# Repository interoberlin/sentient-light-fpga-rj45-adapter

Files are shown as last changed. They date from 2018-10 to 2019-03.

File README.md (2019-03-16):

# Lattice iCEstick adapter with four RJ-45 sockets

The adapter in this repository takes sixteen 3V3 logic level input signals,
converts them to 5V and outputs them on four RJ-45 sockets, four signals per socket,
one signal per twisted pair of an off-the-shelf CAT-5 ethernet cable.
Eight additional inputs can switch the RJ-45 sockets' LEDs on and off.

## Pictures

### Top layer

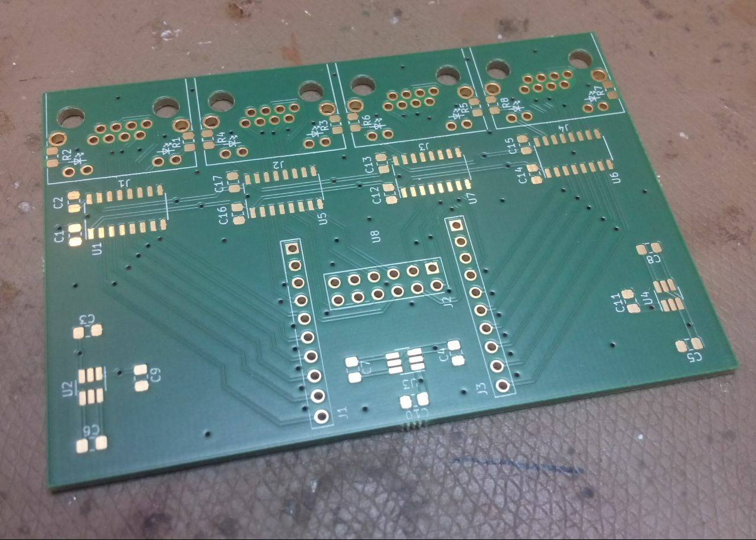
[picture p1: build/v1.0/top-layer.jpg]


### Bottom layer

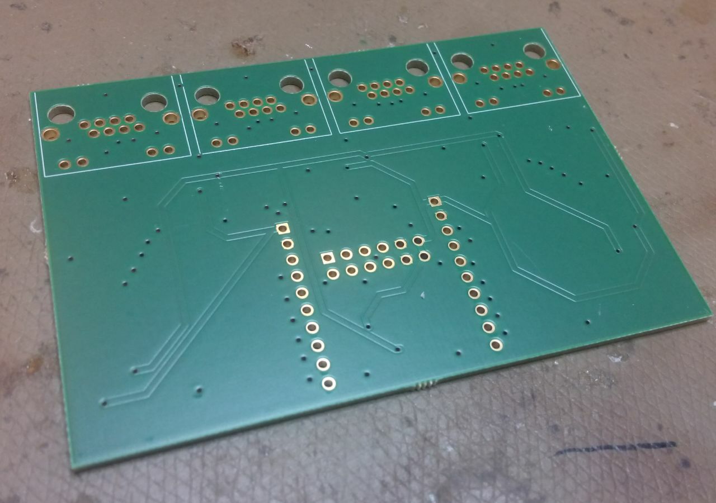
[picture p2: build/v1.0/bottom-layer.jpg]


### With components

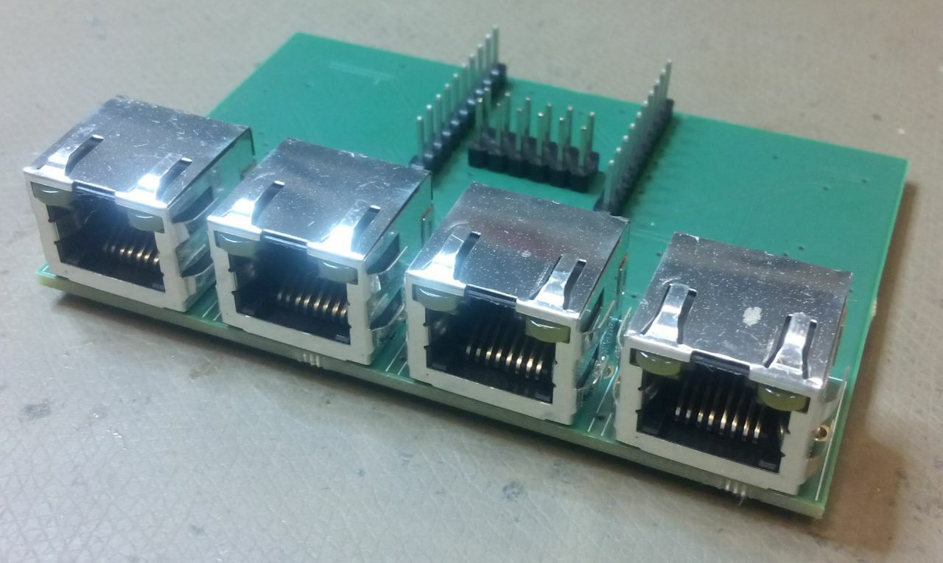
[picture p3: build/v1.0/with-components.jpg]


### With iCEstick

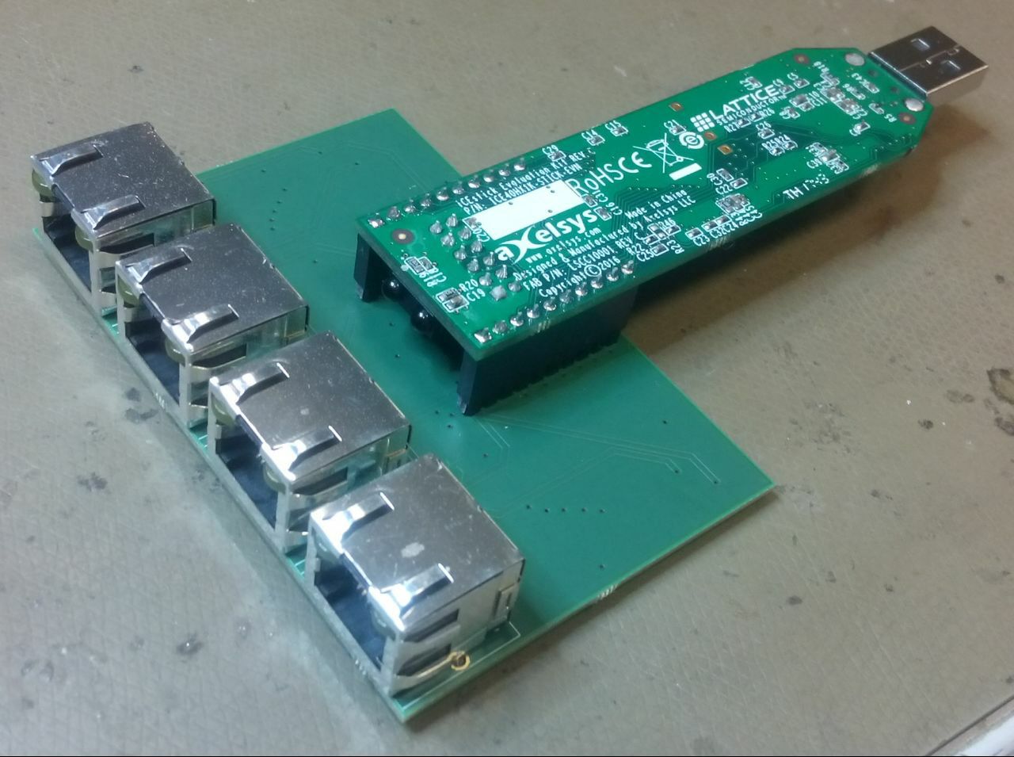
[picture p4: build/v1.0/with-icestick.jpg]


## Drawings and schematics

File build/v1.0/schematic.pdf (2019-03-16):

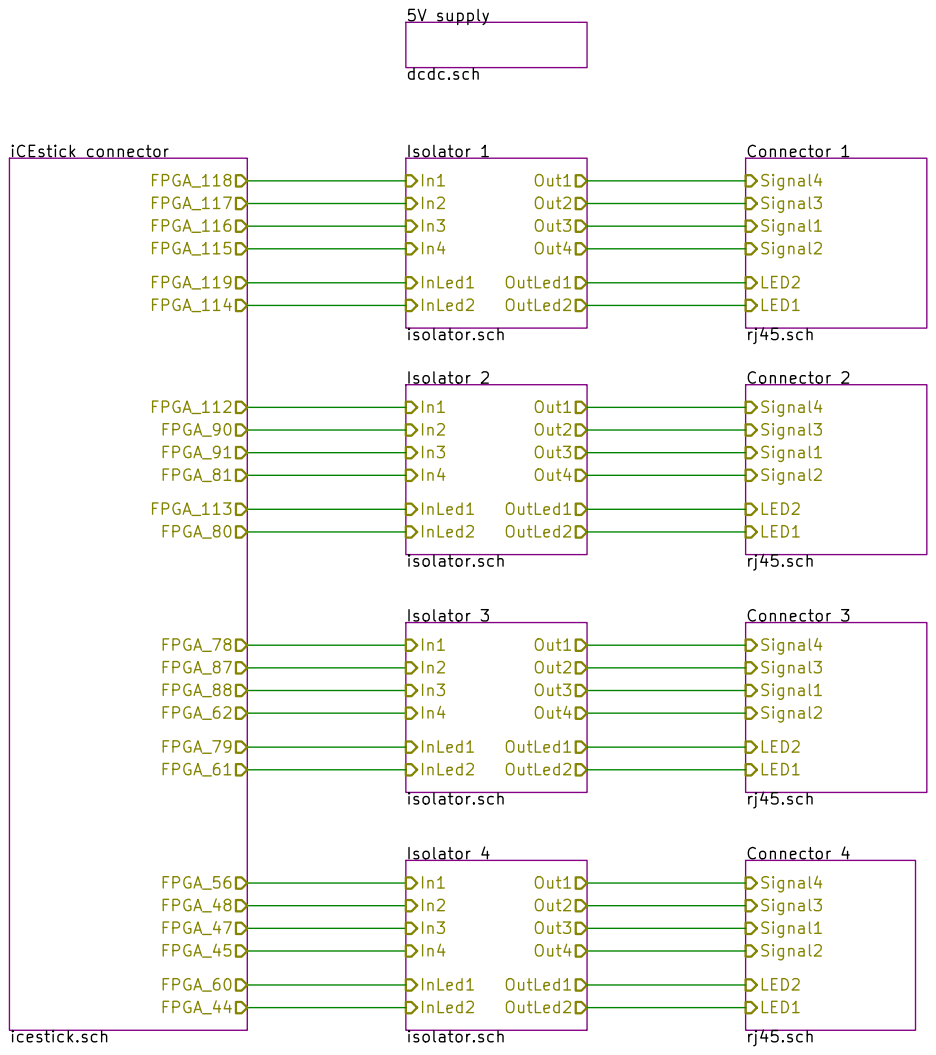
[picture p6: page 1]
6 ABCD; ABCD Date: KiCad E.D.A. kicad 5.0.1+dfsg1-2 Size: A4; Rev:; Id: 1/11 Title:; Isolator 1; isolator.sch; Out1 Out2 Out3 Out4; InLed1; OutLed1; InLed2; OutLed2; Isolator 2; Connector 1; rj45.sch; Signal1 Signal2; Signal3; Signal4; LED1; LED2 Connector 2; LED2 Connector 3; LED2 Connector 4; LED2; Isolator 4; Isolator 3; iCEstick connector; icestick.sch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

5V supply dcdc.sch

File: icestick-rj45-shield.sch Sheet: /

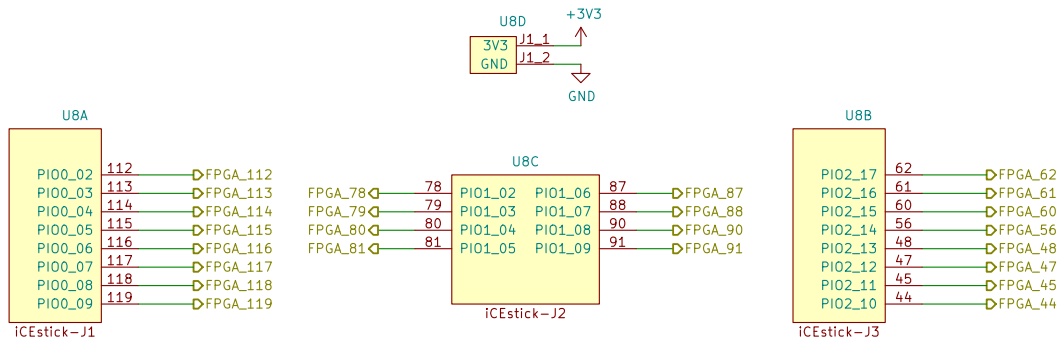
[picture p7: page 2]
D Date: KiCad E.D.A. kicad 5.0.1+dfsg1-2 Size: A4; Rev:; Id: 11/11 Title: File: icestick.sch Sheet: /iCEstick connector/ FPGA_112 FPGA_113 FPGA_114 FPGA_115 FPGA_116 FPGA_117 FPGA_118 FPGA_119; FPGA_62 FPGA_61 FPGA_60 FPGA_56 FPGA_48 FPGA_47 FPGA_45 FPGA_44 GND; FPGA_78 FPGA_79 FPGA_80 FPGA_81; FPGA_87 FPGA_88 FPGA_90 FPGA_91; iCEstick-J1 PIO0_02 112 PIO0_03 113 PIO0_04 114 PIO0_05 115 PIO0_06 116 PIO0_07 117 PIO0_08 118 PIO0_09 119 U8A; iCEstick-J3 PIO2_10; 44 PIO2_11; 45 PIO2_12; 47 PIO2_13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

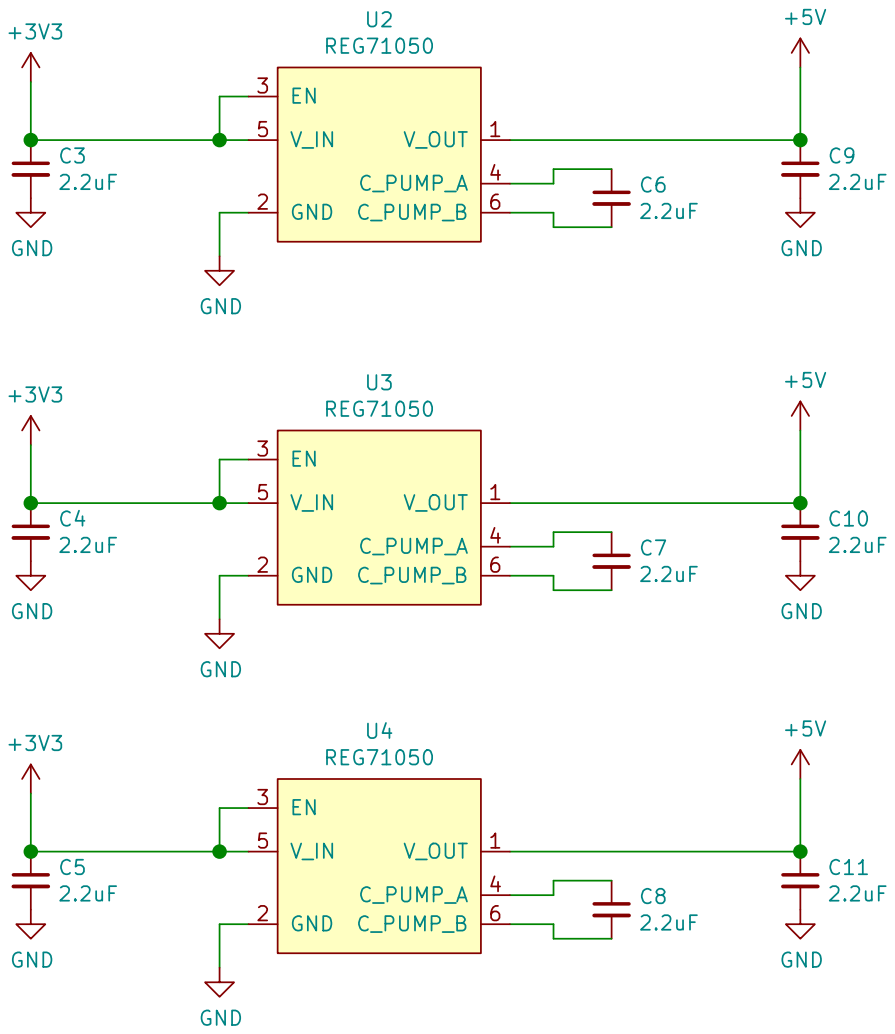
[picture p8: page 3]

Id: 3/11 Title: File: dcdc.sch Sheet: /5V supply/

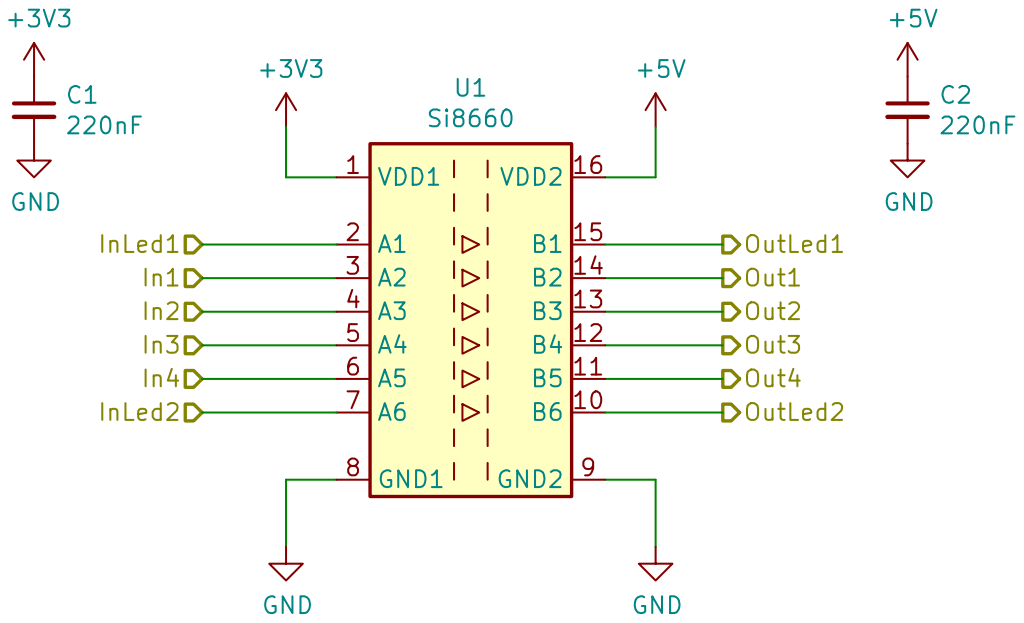
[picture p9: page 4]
D Date: KiCad E.D.A. kicad 5.0.1+dfsg1-2 Size: A4; Rev:; Out1 Out2 Out3 Out4 +3V3; +5V GND; GND; VDD1 1; B6 10 B5 11 B4 12 B3 13 B2 14 B1 15 VDD2 16 A1 2 A2 3 A3 4 A4 5 A5 6 A6 7 GND1 8; GND2 9 U1 Si8660; InLed1; OutLed1; InLed2; OutLed2

Id: 2/11 Title: File: isolator.sch Sheet: /Isolator 1/

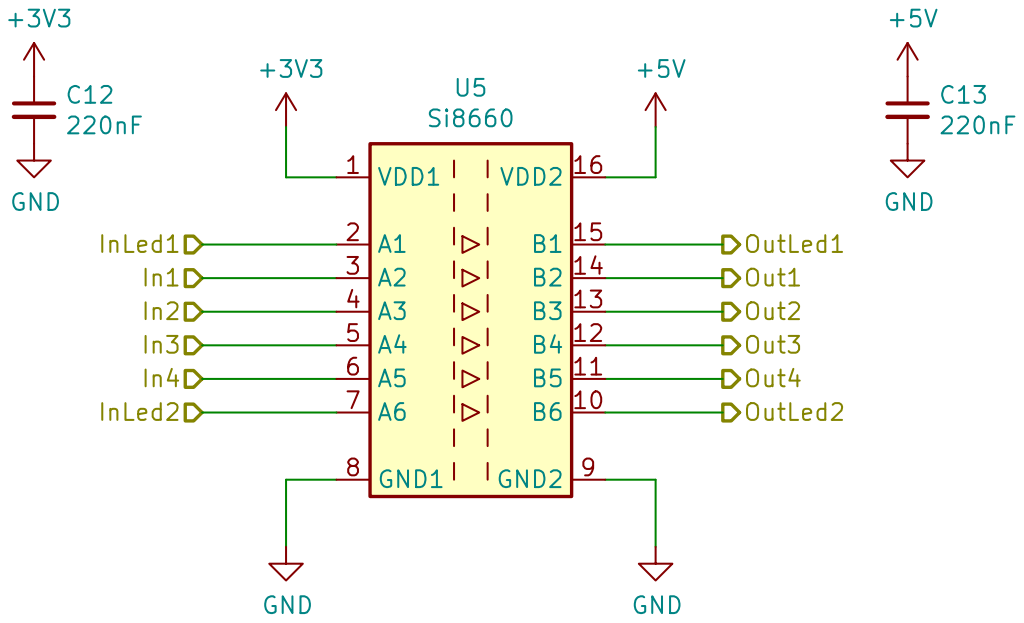
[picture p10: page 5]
D Date: KiCad E.D.A. kicad 5.0.1+dfsg1-2 Size: A4; Rev:; Out1 Out2 Out3 Out4 +3V3; +5V GND; GND; VDD1 1; B6 10 B5 11 B4 12 B3 13 B2 14 B1 15 VDD2 16 A1 2 A2 3 A3 4 A4 5 A5 6 A6 7 GND1 8; GND2 9 U5 Si8660; InLed1; OutLed1; InLed2; OutLed2

Id: 4/11 Title: File: isolator.sch Sheet: /Isolator 2/

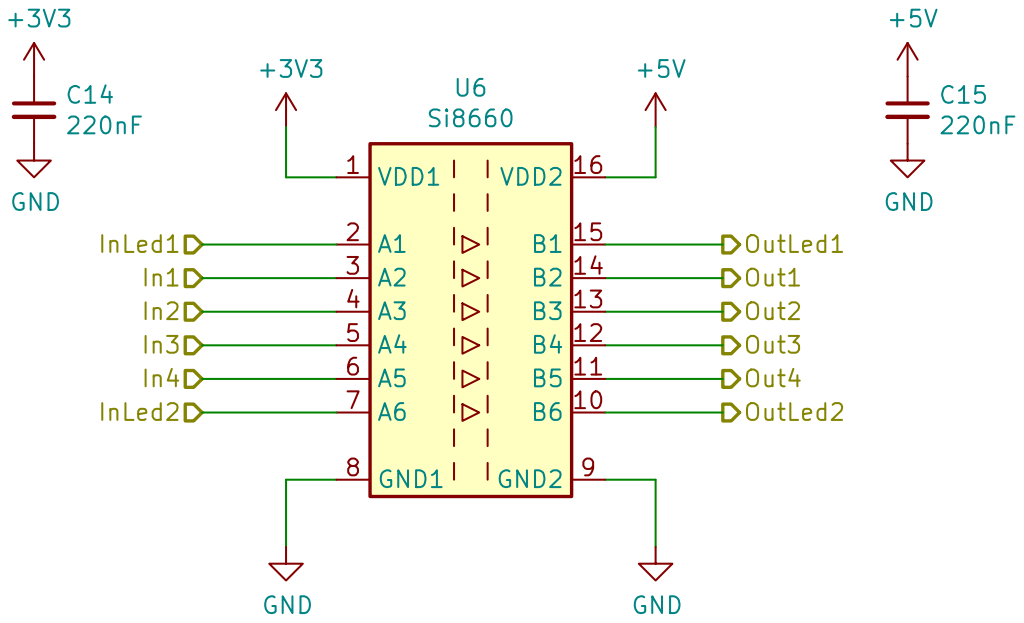
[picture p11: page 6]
D Date: KiCad E.D.A. kicad 5.0.1+dfsg1-2 Size: A4; Rev:; Out1 Out2 Out3 Out4 +3V3; +5V GND; GND; VDD1 1; B6 10 B5 11 B4 12 B3 13 B2 14 B1 15 VDD2 16 A1 2 A2 3 A3 4 A4 5 A5 6 A6 7 GND1 8; GND2 9 U6 Si8660; InLed1; OutLed1; InLed2; OutLed2

Id: 9/11 Title: File: isolator.sch Sheet: /Isolator 4/

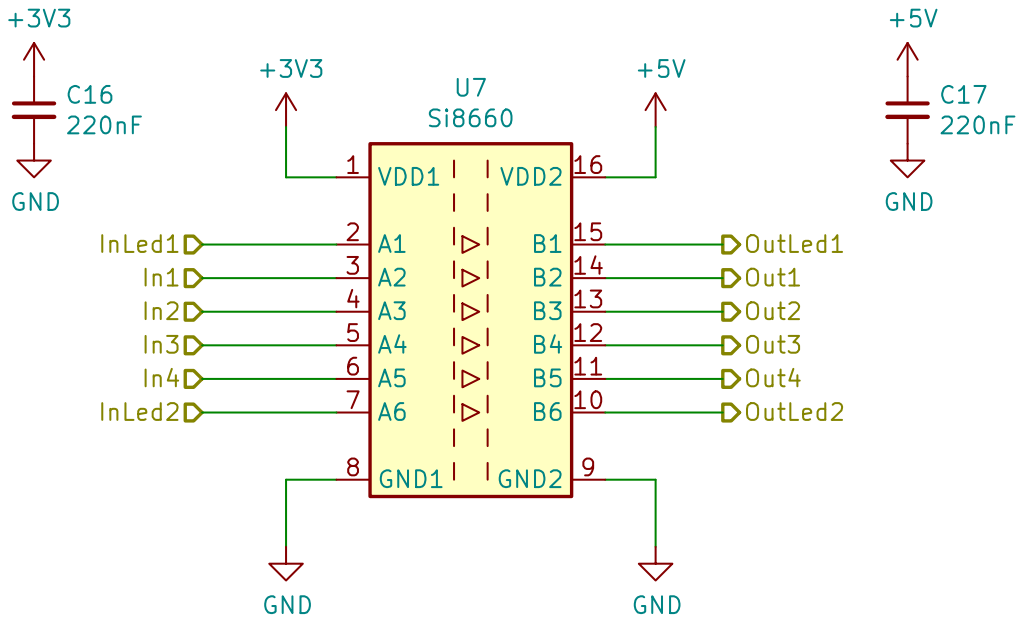
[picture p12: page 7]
D Date: KiCad E.D.A. kicad 5.0.1+dfsg1-2 Size: A4; Rev:; Out1 Out2 Out3 Out4 +3V3; +5V GND; GND; VDD1 1; B6 10 B5 11 B4 12 B3 13 B2 14 B1 15 VDD2 16 A1 2 A2 3 A3 4 A4 5 A5 6 A6 7 GND1 8; GND2 9 U7 Si8660; InLed1; OutLed1; InLed2; OutLed2

Id: 10/11 Title: File: isolator.sch Sheet: /Isolator 3/

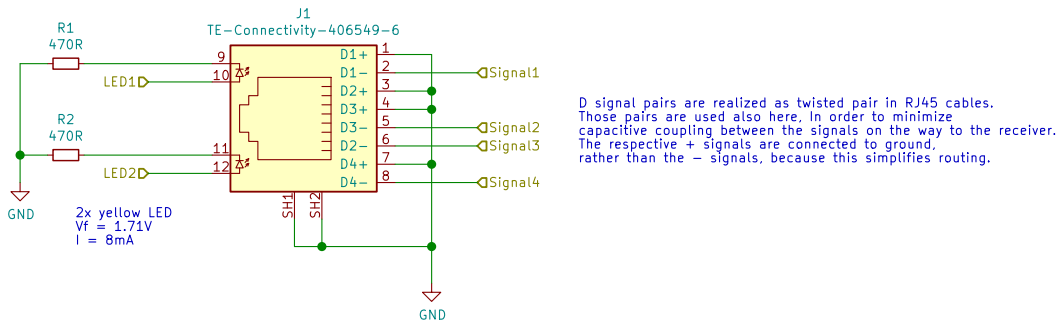
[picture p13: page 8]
D Date: KiCad E.D.A. kicad 5.0.1+dfsg1-2 Size: A4; Rev:; Signal1; Signal2 Signal3; Signal4 GND; LED1; LED2 R1 470R; R2 470R GND; SH¹; SH²; J1 TE-Connectivity-406549-6; 2x yellow LED Vf = 1.71V; D signal pairs are realized as twisted pair in RJ45 cables.

Those pairs are used also here, In order to minimize
capacitive coupling between the signals on the way to the receiver.
The respective + signals are connected to ground,
rather than the - signals, because this simplifies routing.

File: rj45.sch Sheet: /Connector 1/
Id: 5/11 Title:

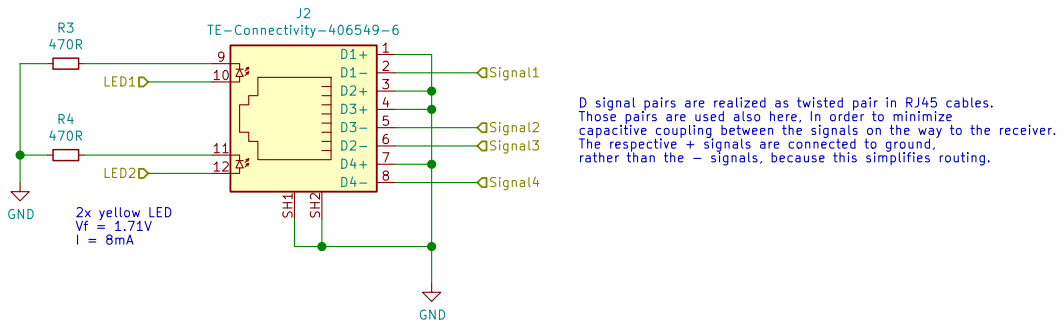
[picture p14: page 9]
D Date: KiCad E.D.A. kicad 5.0.1+dfsg1-2 Size: A4; Rev:; Signal1; Signal2 Signal3; Signal4 GND; LED1; LED2 R3 470R; R4 470R GND; SH¹; SH²; J2 TE-Connectivity-406549-6; 2x yellow LED Vf = 1.71V; D signal pairs are realized as twisted pair in RJ45 cables.

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

File: rj45.sch Sheet: /Connector 2/
Id: 6/11 Title:

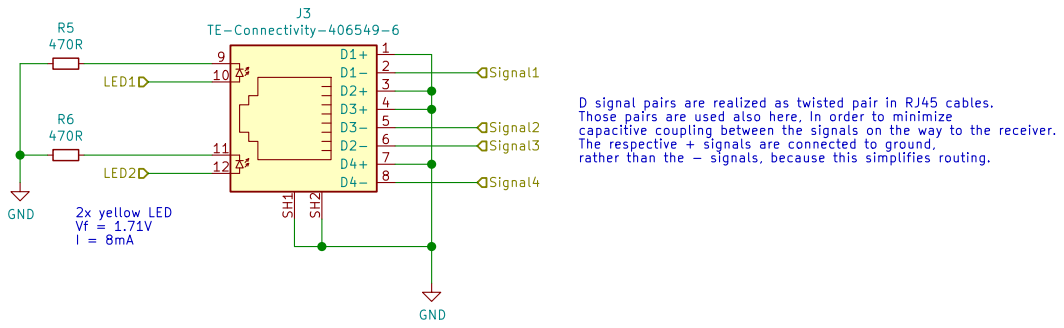
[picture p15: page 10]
D Date: KiCad E.D.A. kicad 5.0.1+dfsg1-2 Size: A4; Rev:; Signal1; Signal2 Signal3; Signal4 GND; LED1; LED2 R5 470R; R6 470R GND; SH¹; SH²; J3 TE-Connectivity-406549-6; 2x yellow LED Vf = 1.71V; D signal pairs are realized as twisted pair in RJ45 cables.

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

File: rj45.sch Sheet: /Connector 3/
Id: 7/11 Title:

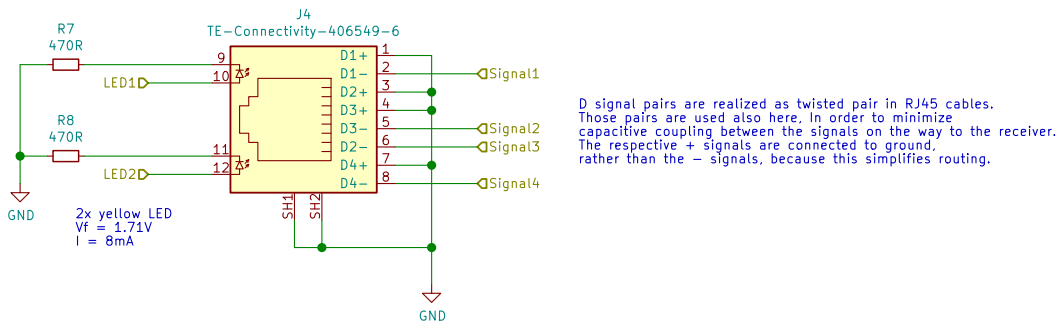
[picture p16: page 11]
D Date: KiCad E.D.A. kicad 5.0.1+dfsg1-2 Size: A4; Rev:; Signal1; Signal2 Signal3; Signal4 GND; LED1; LED2 R7 470R; R8 470R GND; SH¹; SH²; J4 TE-Connectivity-406549-6; 2x yellow LED Vf = 1.71V; D signal pairs are realized as twisted pair in RJ45 cables.

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

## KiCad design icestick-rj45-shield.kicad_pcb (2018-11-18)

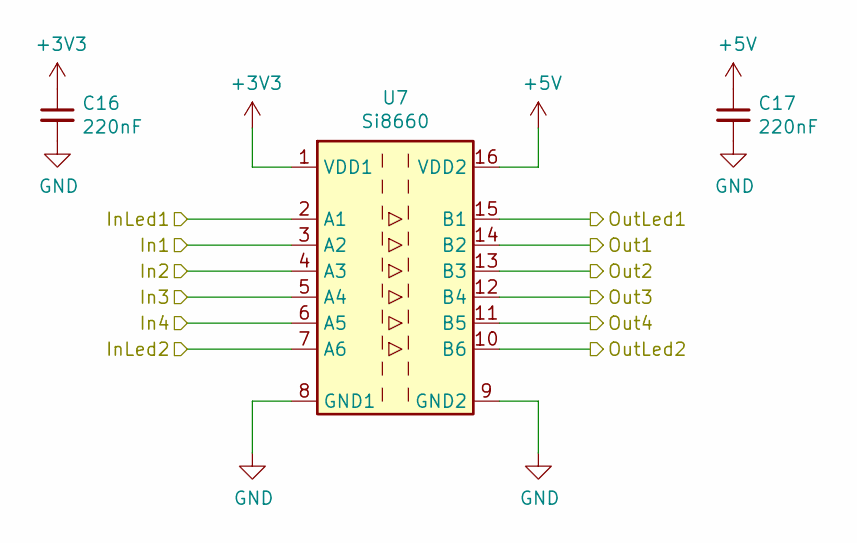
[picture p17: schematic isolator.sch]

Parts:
C1, C2: 220nF; C_0805_2012Metric_Pad1.15x1.40mm_HandSolder
U1: Si8660; SOIC-16_3.9x9.9mm_P1.27mm

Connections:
+3V3: C1.1, U1.1 (VDD1); also elsewhere on the board
+5V: C2.1, U1.16 (VDD2); also elsewhere on the board
/Connector 1/LED1: U1.10 (B6); also elsewhere on the board
/Connector 1/LED2: U1.15 (B1); also elsewhere on the board
/Isolator 1/Out1: U1.14 (B2); also elsewhere on the board
/Isolator 1/Out2: U1.13 (B3); also elsewhere on the board
/Isolator 1/Out3: U1.12 (B4); also elsewhere on the board
/Isolator 1/Out4: U1.11 (B5); also elsewhere on the board
/iCEstick connector/FPGA_114: U1.7 (A6); also elsewhere on the board
/iCEstick connector/FPGA_115: U1.6 (A5); also elsewhere on the board
/iCEstick connector/FPGA_116: U1.5 (A4); also elsewhere on the board
/iCEstick connector/FPGA_117: U1.4 (A3); also elsewhere on the board
/iCEstick connector/FPGA_118: U1.3 (A2); also elsewhere on the board
/iCEstick connector/FPGA_119: U1.2 (A1); also elsewhere on the board
GND: C1.2, C2.2, U1.8 (GND1), U1.9 (GND2); also elsewhere on the board

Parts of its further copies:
C12, C13, C14, C15, C16, C17: 220nF; C_0805_2012Metric_Pad1.15x1.40mm_HandSolder
U5, U6, U7: Si8660; SOIC-16_3.9x9.9mm_P1.27mm

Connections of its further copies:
+3V3: C12.1, C14.1, C16.1, U5.1 (VDD1), U6.1 (VDD1), U7.1 (VDD1); also elsewhere on the board
+5V: C13.1, C15.1, C17.1, U5.16 (VDD2), U6.16 (VDD2), U7.16 (VDD2); also elsewhere on the board
/Connector 2/LED1: U5.10 (B6); also elsewhere on the board
/Connector 2/LED2: U5.15 (B1); also elsewhere on the board
/Connector 3/LED1: U7.10 (B6); also elsewhere on the board
/Connector 3/LED2: U7.15 (B1); also elsewhere on the board
/Connector 4/LED1: U6.10 (B6); also elsewhere on the board
/Connector 4/LED2: U6.15 (B1); also elsewhere on the board
/Isolator 2/Out1: U5.14 (B2); also elsewhere on the board
/Isolator 2/Out2: U5.13 (B3); also elsewhere on the board
/Isolator 2/Out3: U5.12 (B4); also elsewhere on the board
/Isolator 2/Out4: U5.11 (B5); also elsewhere on the board
/Isolator 3/Out1: U7.14 (B2); also elsewhere on the board
/Isolator 3/Out2: U7.13 (B3); also elsewhere on the board
/Isolator 3/Out3: U7.12 (B4); also elsewhere on the board
/Isolator 3/Out4: U7.11 (B5); also elsewhere on the board
/Isolator 4/Out1: U6.14 (B2); also elsewhere on the board
/Isolator 4/Out2: U6.13 (B3); also elsewhere on the board
/Isolator 4/Out3: U6.12 (B4); also elsewhere on the board
/Isolator 4/Out4: U6.11 (B5); also elsewhere on the board
/iCEstick connector/FPGA_44: U6.7 (A6); also elsewhere on the board
/iCEstick connector/FPGA_45: U6.6 (A5); also elsewhere on the board
/iCEstick connector/FPGA_47: U6.5 (A4); also elsewhere on the board
/iCEstick connector/FPGA_48: U6.4 (A3); also elsewhere on the board
/iCEstick connector/FPGA_56: U6.3 (A2); also elsewhere on the board
/iCEstick connector/FPGA_60: U6.2 (A1); also elsewhere on the board
/iCEstick connector/FPGA_61: U7.7 (A6); also elsewhere on the board
/iCEstick connector/FPGA_62: U7.6 (A5); also elsewhere on the board
/iCEstick connector/FPGA_78: U7.3 (A2); also elsewhere on the board
/iCEstick connector/FPGA_79: U7.2 (A1); also elsewhere on the board
/iCEstick connector/FPGA_80: U5.7 (A6); also elsewhere on the board
/iCEstick connector/FPGA_81: U5.6 (A5); also elsewhere on the board
/iCEstick connector/FPGA_87: U7.4 (A3); also elsewhere on the board
/iCEstick connector/FPGA_88: U7.5 (A4); also elsewhere on the board
/iCEstick connector/FPGA_90: U5.4 (A3); also elsewhere on the board
/iCEstick connector/FPGA_91: U5.5 (A4); also elsewhere on the board
/iCEstick connector/FPGA_112: U5.3 (A2); also elsewhere on the board
/iCEstick connector/FPGA_113: U5.2 (A1); also elsewhere on the board
GND: C12.2, C13.2, C14.2, C15.2, C16.2, C17.2, U5.8 (GND1), U5.9 (GND2), U6.8 (GND1), U6.9 (GND2), U7.8 (GND1), U7.9 (GND2); also elsewhere on the board

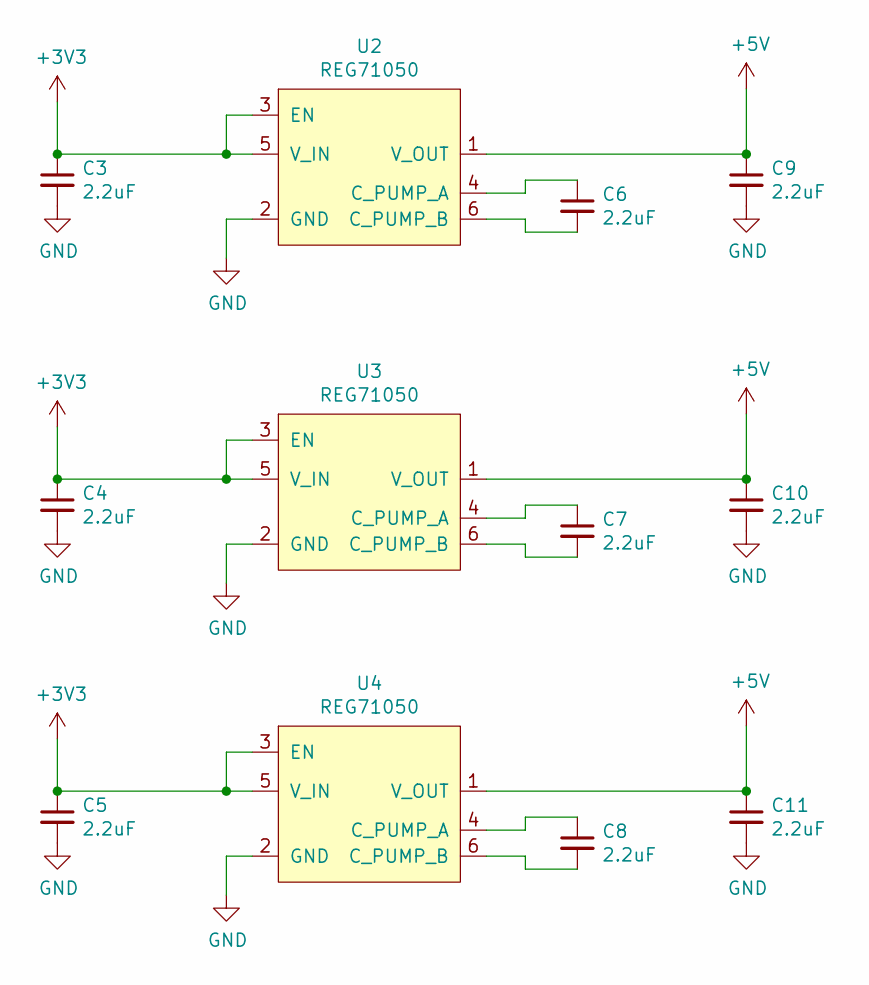
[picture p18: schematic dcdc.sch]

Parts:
C3, C4, C5, C6, C7, C8, C9, C10, C11: 2.2uF; C_0805_2012Metric_Pad1.15x1.40mm_HandSolder
U2, U3, U4: REG71050; SOT-23-6_Handsoldering

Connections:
+3V3: C3.1, C4.1, C5.1, U2.3 (EN), U2.5 (V_IN), U3.3 (EN), U3.5 (V_IN), U4.3 (EN), U4.5 (V_IN); also elsewhere on the board
+5V: C9.1, C10.1, C11.1, U2.1 (V_OUT), U3.1 (V_OUT), U4.1 (V_OUT); also elsewhere on the board
GND: C3.2, C4.2, C5.2, C9.2, C10.2, C11.2, U2.2 (GND), U3.2 (GND), U4.2 (GND); also elsewhere on the board
unnamed: C6.1, U2.4 (C_PUMP_A)
unnamed: C6.2, U2.6 (C_PUMP_B)
unnamed: C7.1, U3.4 (C_PUMP_A)
unnamed: C7.2, U3.6 (C_PUMP_B)
unnamed: C8.1, U4.4 (C_PUMP_A)
unnamed: C8.2, U4.6 (C_PUMP_B)

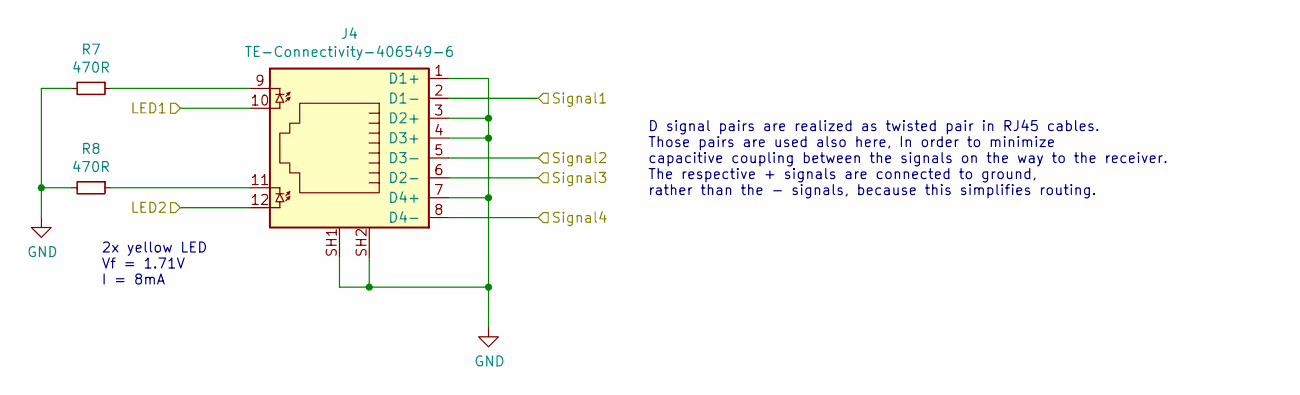
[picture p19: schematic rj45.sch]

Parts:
J2: TE-Connectivity-406549-6
R1, R2: 470R; R_0805_2012Metric_Pad1.15x1.40mm_HandSolder

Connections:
/Connector 2/LED1: J2.10; also elsewhere on the board
/Connector 2/LED2: J2.12; also elsewhere on the board
/Isolator 2/Out1: J2.8 (D4-); also elsewhere on the board
/Isolator 2/Out2: J2.6 (D2-); also elsewhere on the board
/Isolator 2/Out3: J2.2 (D1-); also elsewhere on the board
/Isolator 2/Out4: J2.5 (D3-); also elsewhere on the board
GND: J2.1 (D1+), J2.3 (D2+), J2.4 (D3+), J2.7 (D4+), J2.SH1, J2.SH2, R1.2, R2.2; also elsewhere on the board

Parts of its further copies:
J1, J3, J4: TE-Connectivity-406549-6
R3, R4, R5, R6, R7, R8: 470R; R_0805_2012Metric_Pad1.15x1.40mm_HandSolder

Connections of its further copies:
/Connector 1/LED1: J1.10; also elsewhere on the board
/Connector 1/LED2: J1.12; also elsewhere on the board
/Connector 3/LED1: J3.10; also elsewhere on the board
/Connector 3/LED2: J3.12; also elsewhere on the board
/Connector 4/LED1: J4.10; also elsewhere on the board
/Connector 4/LED2: J4.12; also elsewhere on the board
/Isolator 1/Out1: J1.8 (D4-); also elsewhere on the board
/Isolator 1/Out2: J1.6 (D2-); also elsewhere on the board
/Isolator 1/Out3: J1.2 (D1-); also elsewhere on the board
/Isolator 1/Out4: J1.5 (D3-); also elsewhere on the board
/Isolator 3/Out1: J3.8 (D4-); also elsewhere on the board
/Isolator 3/Out2: J3.6 (D2-); also elsewhere on the board
/Isolator 3/Out3: J3.2 (D1-); also elsewhere on the board
/Isolator 3/Out4: J3.5 (D3-); also elsewhere on the board
/Isolator 4/Out1: J4.8 (D4-); also elsewhere on the board
/Isolator 4/Out2: J4.6 (D2-); also elsewhere on the board
/Isolator 4/Out3: J4.2 (D1-); also elsewhere on the board
/Isolator 4/Out4: J4.5 (D3-); also elsewhere on the board
GND: J1.1 (D1+), J1.3 (D2+), J1.4 (D3+), J1.7 (D4+), J1.SH1, J1.SH2, J3.1 (D1+), J3.3 (D2+), J3.4 (D3+), J3.7 (D4+), J3.SH1, J3.SH2, J4.1 (D1+), J4.3 (D2+), J4.4 (D3+), J4.7 (D4+), J4.SH1, J4.SH2, R3.2, R4.2, R5.2, R6.2, R7.2, R8.2; also elsewhere on the board
unnamed: J3.9, R5.1
unnamed: J3.11, R6.1
unnamed: J4.9, R7.1
unnamed: J4.11, R8.1

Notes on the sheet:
2x yellow LED Vf = 1.71V I = 8mA
D signal pairs are realized as twisted pair in RJ45 cables. Those pairs are used also here, In order to minimize capacitive coupling between the signals on the way to the receiver. The respective + signals are connected to ground, rather than the - signals, because this simplifies routing.

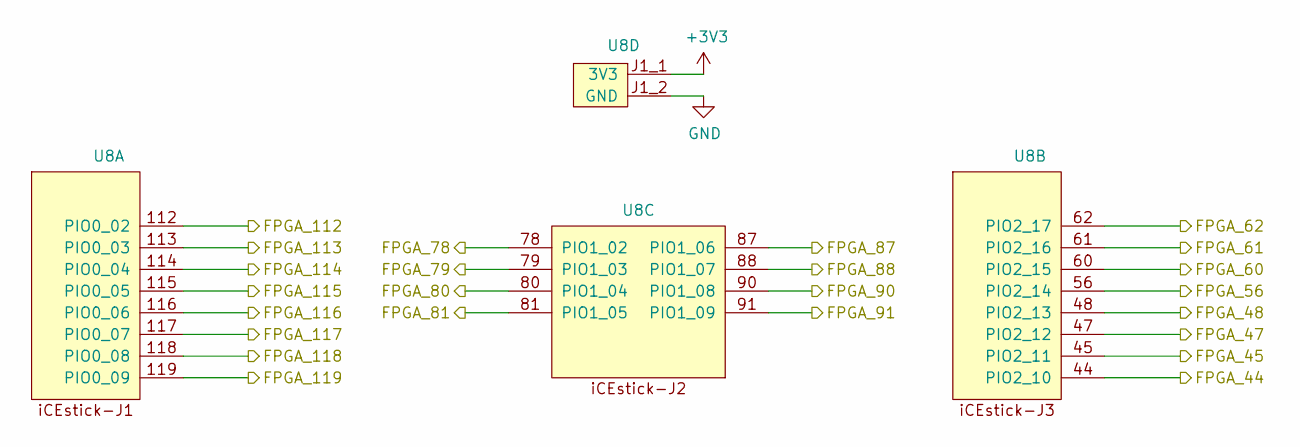
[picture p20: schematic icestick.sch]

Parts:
U8: iCEstick

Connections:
+3V3: U8.J1_1 (3V3), U8.J2_6 (3V3), U8.J2_12 (3V3), U8.J3_1 (3V3); also elsewhere on the board
/iCEstick connector/FPGA_44: U8.44 (PIO2_10); also elsewhere on the board
/iCEstick connector/FPGA_45: U8.45 (PIO2_11); also elsewhere on the board
/iCEstick connector/FPGA_47: U8.47 (PIO2_12); also elsewhere on the board
/iCEstick connector/FPGA_48: U8.48 (PIO2_13); also elsewhere on the board
/iCEstick connector/FPGA_56: U8.56 (PIO2_14); also elsewhere on the board
/iCEstick connector/FPGA_60: U8.60 (PIO2_15); also elsewhere on the board
/iCEstick connector/FPGA_61: U8.61 (PIO2_16); also elsewhere on the board
/iCEstick connector/FPGA_62: U8.62 (PIO2_17); also elsewhere on the board
/iCEstick connector/FPGA_78: U8.78 (PIO1_02); also elsewhere on the board
/iCEstick connector/FPGA_79: U8.79 (PIO1_03); also elsewhere on the board
/iCEstick connector/FPGA_80: U8.80 (PIO1_04); also elsewhere on the board
/iCEstick connector/FPGA_81: U8.81 (PIO1_05); also elsewhere on the board
/iCEstick connector/FPGA_87: U8.87 (PIO1_06); also elsewhere on the board
/iCEstick connector/FPGA_88: U8.88 (PIO1_07); also elsewhere on the board
/iCEstick connector/FPGA_90: U8.90 (PIO1_08); also elsewhere on the board
/iCEstick connector/FPGA_91: U8.91 (PIO1_09); also elsewhere on the board
/iCEstick connector/FPGA_112: U8.112 (PIO0_02); also elsewhere on the board
/iCEstick connector/FPGA_113: U8.113 (PIO0_03); also elsewhere on the board
/iCEstick connector/FPGA_114: U8.114 (PIO0_04); also elsewhere on the board
/iCEstick connector/FPGA_115: U8.115 (PIO0_05); also elsewhere on the board
/iCEstick connector/FPGA_116: U8.116 (PIO0_06); also elsewhere on the board
/iCEstick connector/FPGA_117: U8.117 (PIO0_07); also elsewhere on the board
/iCEstick connector/FPGA_118: U8.118 (PIO0_08); also elsewhere on the board
/iCEstick connector/FPGA_119: U8.119 (PIO0_09); also elsewhere on the board
GND: U8.J1_2 (GND), U8.J2_5 (GND), U8.J2_11 (GND), U8.J3_2 (GND); also elsewhere on the board

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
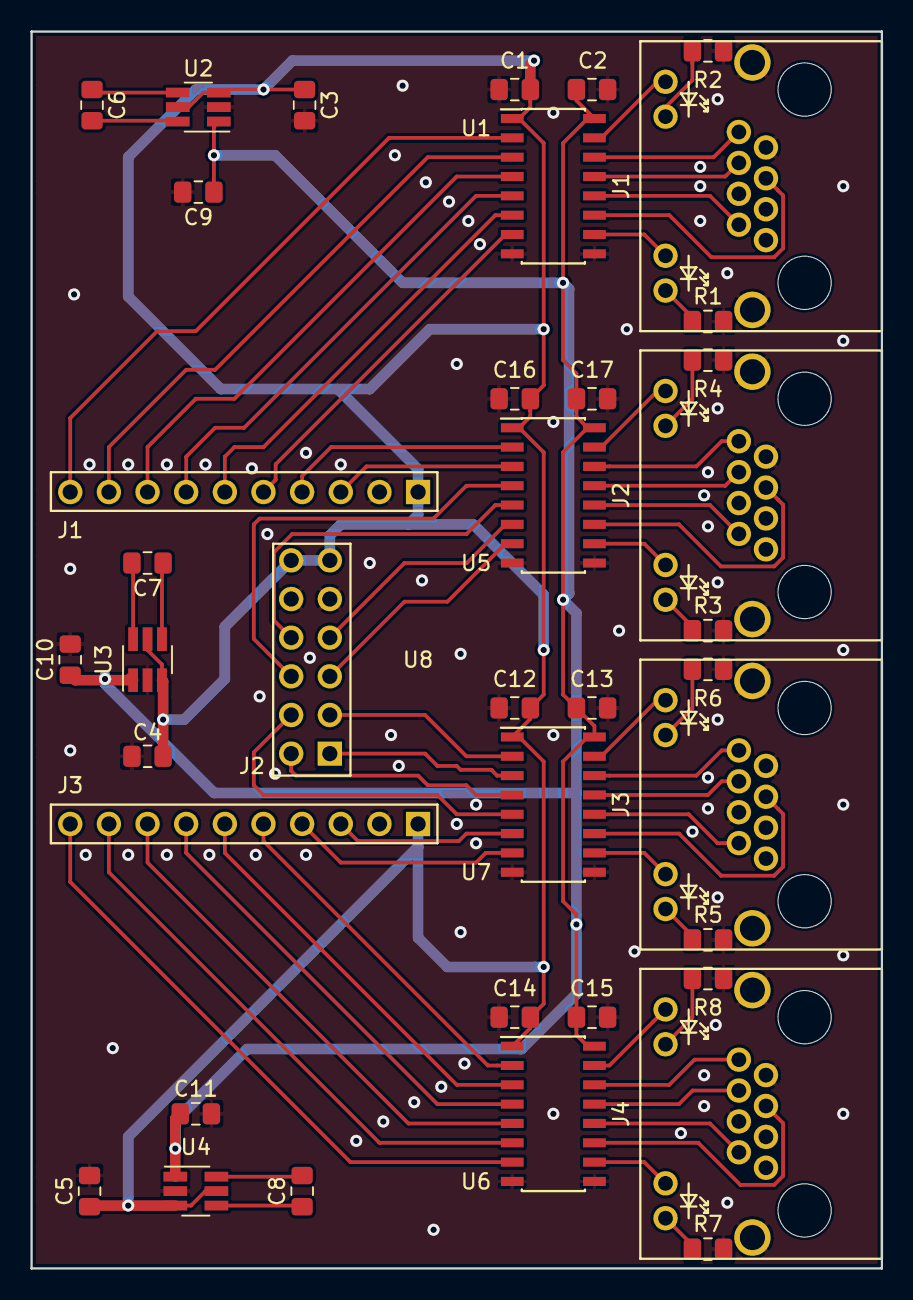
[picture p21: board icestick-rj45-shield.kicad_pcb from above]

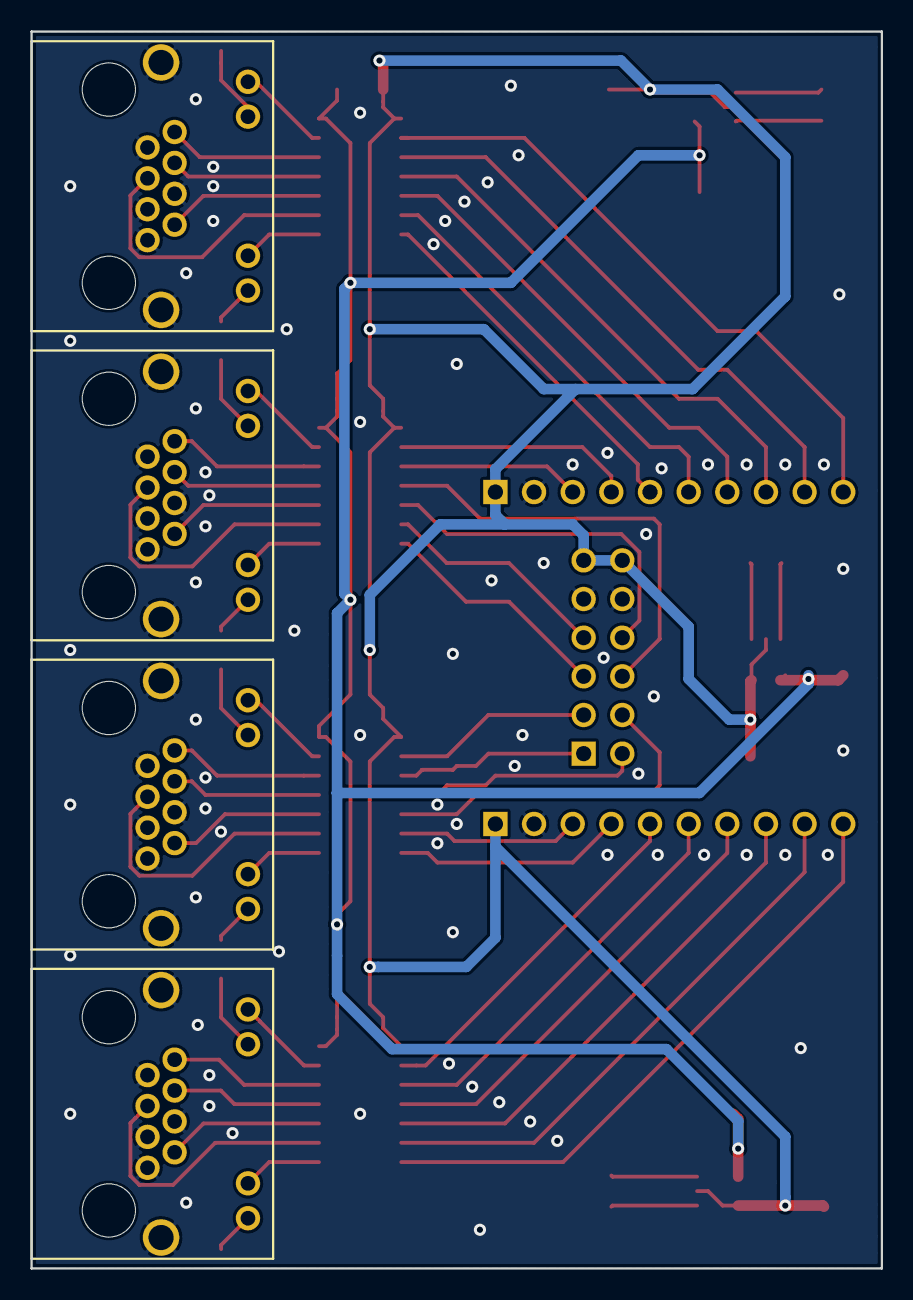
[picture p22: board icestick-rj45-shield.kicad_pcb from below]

Board: 2 copper layers, 55.9 x 81.3 mm, 37 parts (4 on the bottom side), 65 nets.

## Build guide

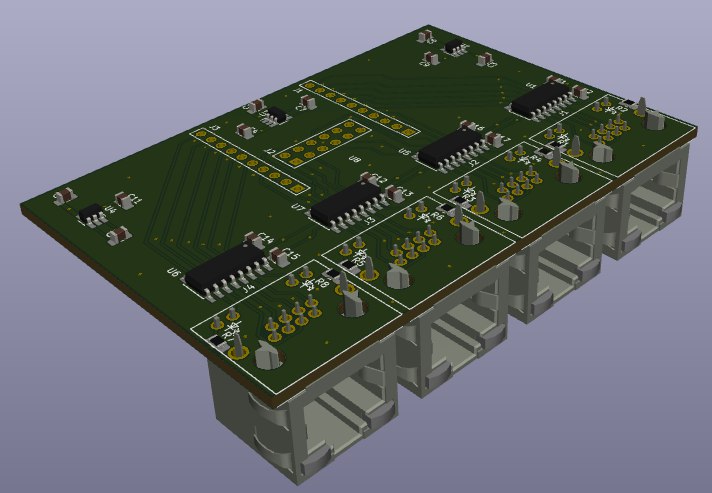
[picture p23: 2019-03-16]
build/v1.0/3d.jpg

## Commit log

2018-10-21 Created empty KiCad 5.0 project
    [icestick-rj45-shield.kicad_pcb, icestick-rj45-shield.sch]
2018-10-21 Added iCEstick schematic in folder doc/
2018-10-21 icestick.sch: Added headers J1 and J3
    [dcdc.sch, icestick-rj45-shield.sch, icestick.sch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]
2018-10-21 Fixed sheet relations (no separate projects but sub-sheets)
    [dcdc.sch, icestick-rj45-shield.sch, icestick.sch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]
2018-10-21 Added library for project specific symbols
    [icestick-rj45-shield.sch, isolator.sch]
2018-10-21 Added isolators and RJ-45 connectors
    [dcdc.sch, icestick-rj45-shield.sch, icestick.sch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]
2018-10-21 Added Texas Instruments REG710xx charge pump IC datasheet
2018-10-21 Added charge pump IC REG71050
    [dcdc.sch, icestick-rj45-shield.sch, icestick.sch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]
2018-10-21 Added symbol library table for my symbol library
    [icestick-rj45-shield.sch]
2018-10-21 Assigned footprints
    [dcdc.sch, icestick.sch, isolator.sch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]
2018-10-21 Began layouting
    [dcdc.sch, icestick-rj45-shield.kicad_pcb, isolator.sch]
2018-10-23 Continued layouting
    [dcdc.sch, icestick-rj45-shield.kicad_pcb, icestick-rj45-shield.sch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]
2018-10-24 Fixed iCEstick header distance
    [icestick-rj45-shield.kicad_pcb]
2018-10-24 Routed all the signals
    [icestick-rj45-shield.kicad_pcb, icestick-rj45-shield.sch, isolator.sch]
2018-10-25 PCB: Added a couple of GND vias
    [icestick-rj45-shield.kicad_pcb]
2018-11-05 Switched to Si8660 isolator and changed RJ-45 connector
    [icestick-rj45-shield.kicad_pcb, isolator.sch, rj45.sch]
2018-11-06 Updated RJ45 symbol and corresponding signal names
    [dcdc.sch, icestick-rj45-shield.sch, isolator.sch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]
2018-11-10 Began redesigning with Si8660
    [dcdc.sch, icestick-rj45-shield.kicad_pcb, icestick-rj45-shield.sch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]
2018-11-18 Finished layout with 4x Si8660
    [icestick-rj45-shield.kicad_pcb, icestick-rj45-shield.sch, icestick.sch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]
2018-11-18 Moved PCB outline measures to Drawings layer
    [icestick-rj45-shield.kicad_pcb]
2018-11-18 Exported fabrication files (Gerber)
    [icestick-rj45-shield-B.Cu.gbr, icestick-rj45-shield-B.Mask.gbr, icestick-rj45-shield-B.SilkS.gbr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]
2018-11-27 Added my KiCad libraries as submodule
2018-11-29 Added README.md with PCB pictures
2019-03-16 Added schematic PDF, 3d rendering and STEP model
    [icestick-rj45-shield-B.Cu.gbr, icestick-rj45-shield-B.Mask.gbr, icestick-rj45-shield-B.SilkS.gbr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]
